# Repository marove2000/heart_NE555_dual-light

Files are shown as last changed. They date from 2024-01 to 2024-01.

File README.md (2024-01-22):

# Heart SMD NE555
24 LEDs forming a LED-Heart driven by a NE555 bistable vibrator. A LED-Light runs around the heart. The speed of the running LED-light can be modified by the potentiomenter
This soldering Kit requires first experience in SMD-Soldering and is a very good practice for the size 0805.

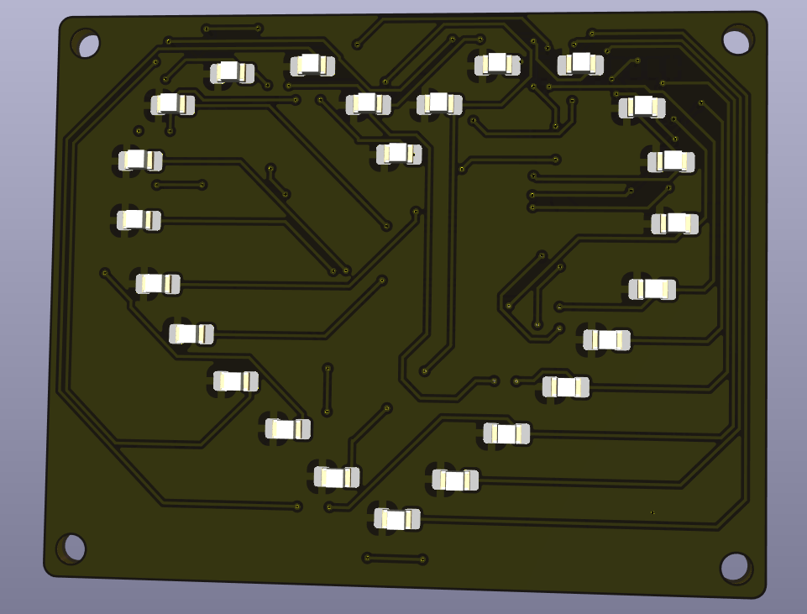
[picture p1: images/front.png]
Heart SMD NE555 dual-led
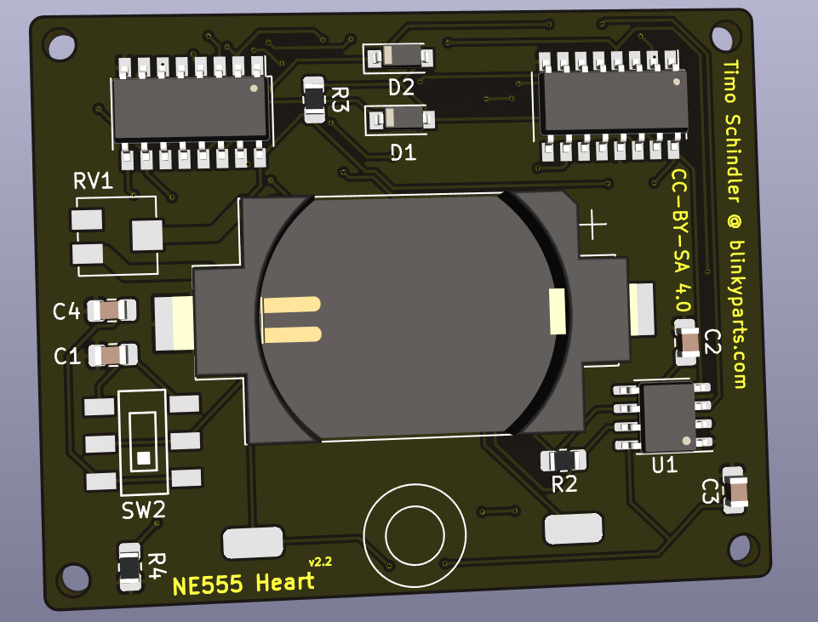
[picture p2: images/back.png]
Heart SMD NE555 dual led
 

- Status: **Complete**
- Difficulty: **3/5**

### Parts List

| Description |  Name  | Quantity |
|---|:---:|:---:|
| SMD LED 0805 red | D5-D28 | 24 |
| SMD Capacitor 10nF | C1 | 1 |
| SMD Capacitor 100n |  C2,C3 | 2 |
| SMD Capacitor 1uF		| C4	 | 1 |
| SMD Diode 1N4007 |  D1-D2 | 2 |
| SMD Push Button | SW1  | 1 |
| SMD Sliding Switch | SW2  | 1 |
| RV1 Potentiometer | RV1  | 1 |
| SMD Resistor 0805 1k | R2 | 1 |
| SMD Resistor 0805 100k | R3 | 1 |
| SMD Resistor 0805 47R | R5 | 1 |
| NE555 SOIC-8 | U1 | 1 |
| CD4017 SOP-16 |  U2,U3 | 2 |
| CR2032 Battery Holder (SMD) | BT1  | 1 |
| CR2032 Battery (not included) | | 1 |

### Manual
You can find the manual and pictures of every step here: https://github.com/Binary-Kitchen/SolderingTutorial

### Buy Kits

You can also buy a ready to make soldering-kit @ [shop.blinkyparts.com](https://shop.blinkyparts.com/de/SMD-LED-Herz-mit-NE555-SMD-Bausatz-mit-Herz/blink232542).

### Copyright and Authorship

- Board: [CC-BY-SA 4.0](https://creativecommons.org/licenses/by-sa/4.0/) - [Timo Schindler @ blinkyparts.com](https://shop.blinkyparts.com)
- CR2032 battery holder footprint: [CC-BY 4.0](https://creativecommons.org/licenses/by/4.0/) - Sparkfun (https://github.com/sparkfun/SparkFun-KiCad-Libraries)

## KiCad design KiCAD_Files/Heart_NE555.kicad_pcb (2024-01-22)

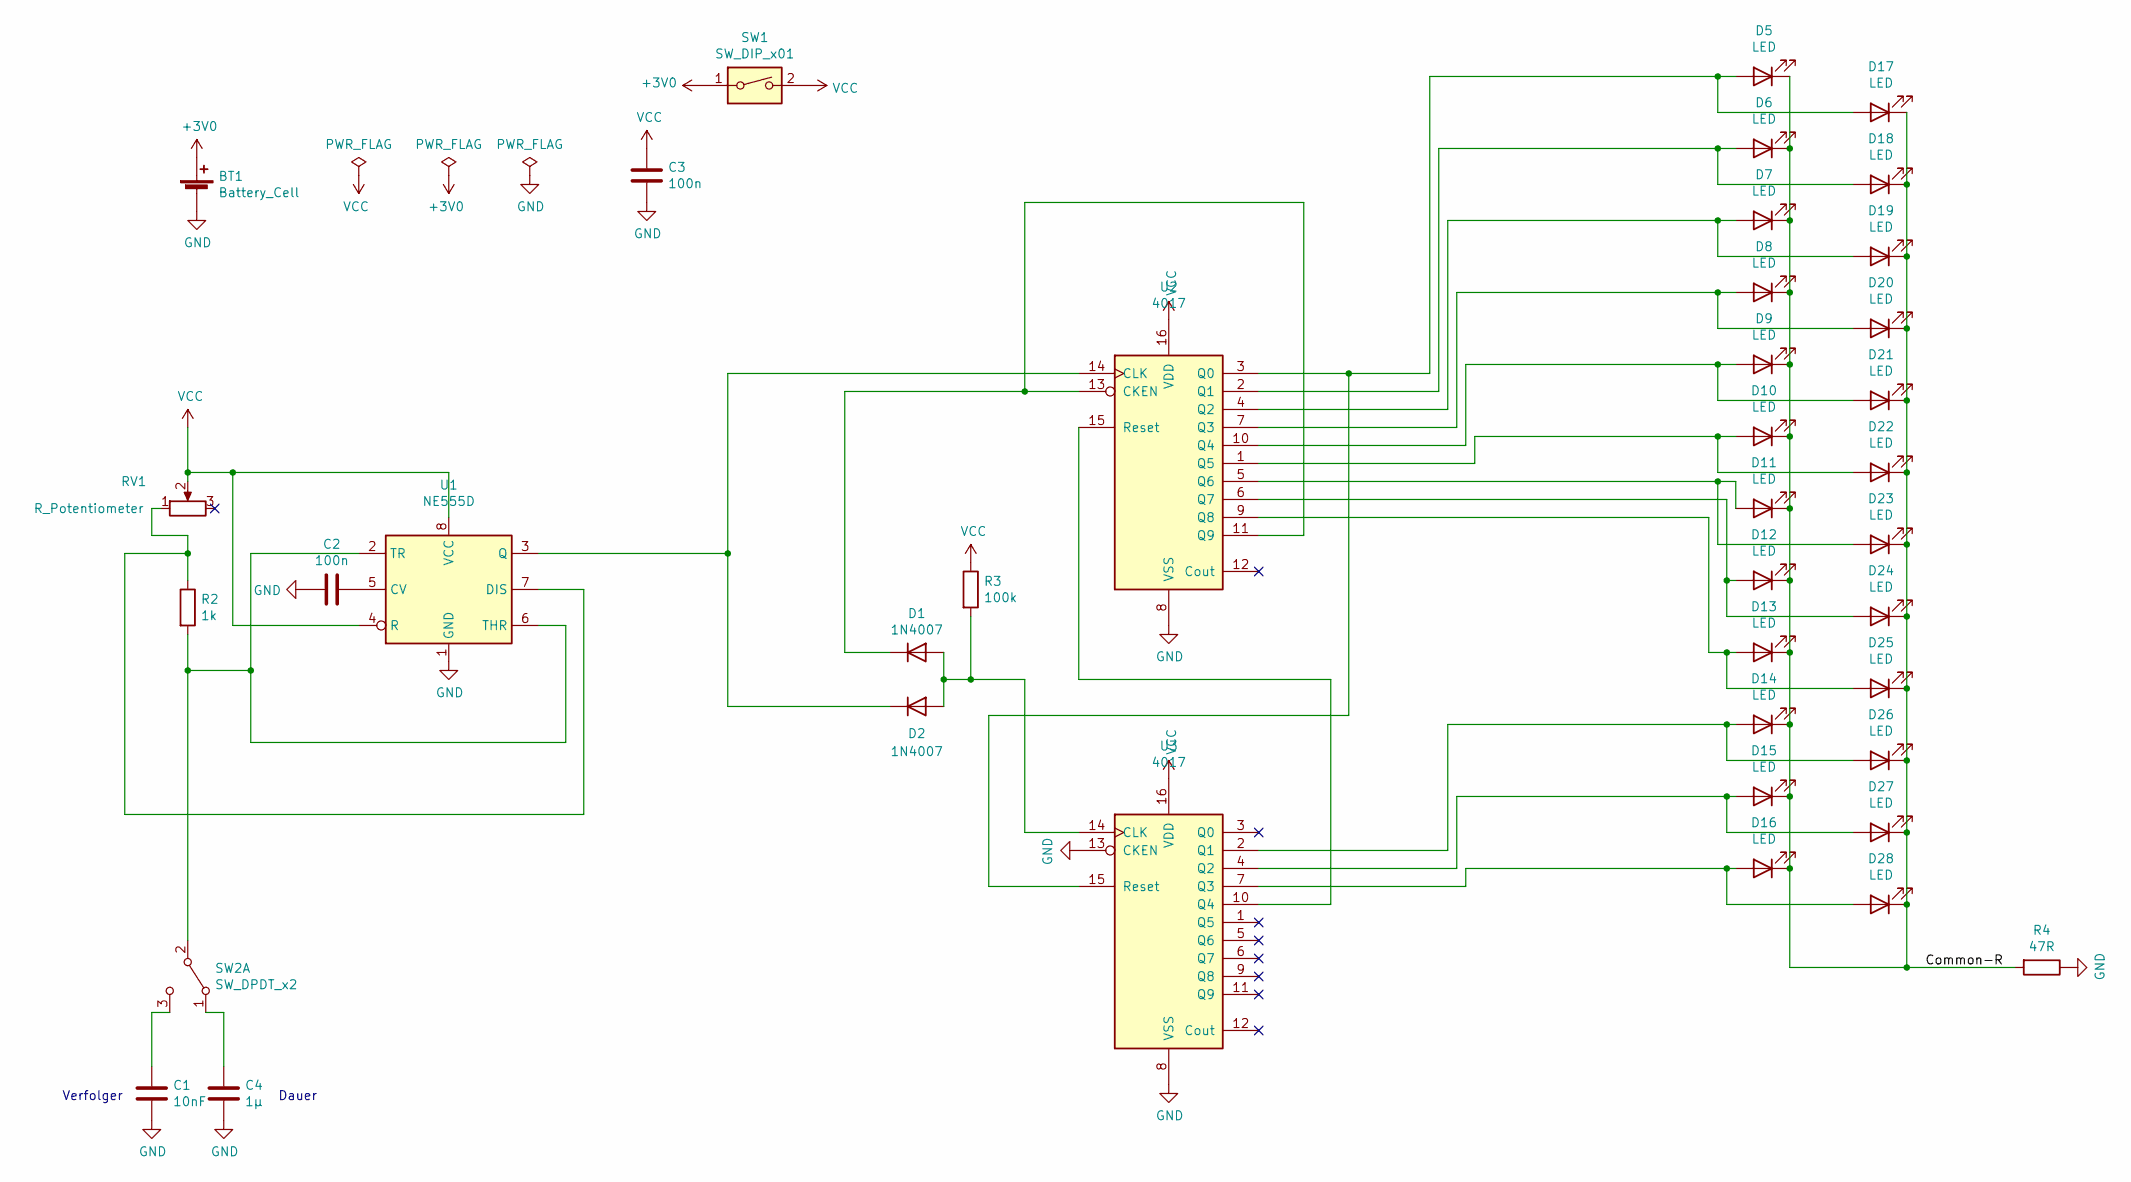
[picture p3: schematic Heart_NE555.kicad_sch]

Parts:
BT1: Battery_Cell; BatteryHolder_Keystone_1060_1x2032_HandSoldering
C1: 10nF; C_0805_2012Metric_Pad1.18x1.45mm_HandSolder
C2, C3: 100n; C_0805_2012Metric_Pad1.18x1.45mm_HandSolder
C4: 1µ; C_0805_2012Metric_Pad1.18x1.45mm_HandSolder
D1, D2: 1N4007; D_SOD-123_handsolder
D5, D6, D7, D8, D9, D10, D11, D12, D13, D14, D15, D16, D17, D18, D19, D20, D21, D22, D23, D24, D25, D26, D27, D28: LED; LED_0805_2012Metric_Pad1.15x1.40mm_HandSolder
R2: 1k; R_0805_2012Metric_Pad1.20x1.40mm_HandSolder
R3: 100k; R_0805_2012Metric_Pad1.20x1.40mm_HandSolder
R4: 47R; R_0805_2012Metric_Pad1.20x1.40mm_HandSolder
RV1: R_Potentiometer; Potentiometer_Vishay_TS53YJ_Vertical
SW1: SW_DIP_x01; Push_Button
SW2: SW_DPDT_x2; smd_switch_slide
U1: NE555D; SOIC-8_3.9x4.9mm_P1.27mm
U2, U3: 4017; SOP-16_4.4x10.4mm_P1.27mm

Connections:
+3V0: BT1.1 (+), SW1.1
/Common-R: D5.1 (K), D6.1 (K), D7.1 (K), D8.1 (K), D9.1 (K), D10.1 (K), D11.1 (K), D12.1 (K), D13.1 (K), D14.1 (K), D15.1 (K), D16.1 (K), D17.1 (K), D18.1 (K), D19.1 (K), D20.1 (K), D21.1 (K), D22.1 (K), D23.1 (K), D24.1 (K), D25.1 (K), D26.1 (K), D27.1 (K), D28.1 (K), R4.2
GND: BT1.2 (-), C1.2, C2.2, C3.2, C4.2, R4.1, U1.1 (GND), U2.8 (VSS), U3.8 (VSS), U3.13 (CKEN)
unnamed: C1.1, SW2.3 (C)
unnamed: C2.1, U1.5 (CV)
unnamed: C4.1, SW2.1 (A)
unnamed: D1.1 (K), U2.11 (Q9), U2.13 (CKEN)
unnamed: D1.2 (A), D2.2 (A), R3.2, U3.14 (CLK)
unnamed: D2.1 (K), U1.3 (Q), U2.14 (CLK)
unnamed: D10.2 (A), D22.2 (A), U2.1 (Q5)
unnamed: D11.2 (A), D23.2 (A), U2.5 (Q6)
unnamed: D12.2 (A), D24.2 (A), U2.6 (Q7)
unnamed: D13.2 (A), D25.2 (A), U2.9 (Q8)
unnamed: D14.2 (A), D26.2 (A), U3.2 (Q1)
unnamed: D15.2 (A), D27.2 (A), U3.4 (Q2)
unnamed: D16.2 (A), D28.2 (A), U3.7 (Q3)
unnamed: D5.2 (A), D17.2 (A), U2.3 (Q0), U3.15 (Reset)
unnamed: D6.2 (A), D18.2 (A), U2.2 (Q1)
unnamed: D7.2 (A), D19.2 (A), U2.4 (Q2)
unnamed: D8.2 (A), D20.2 (A), U2.7 (Q3)
unnamed: D9.2 (A), D21.2 (A), U2.10 (Q4)
unnamed: R2.1, RV1.1, U1.7 (DIS)
unnamed: R2.2, SW2.2 (B), U1.2 (TR), U1.6 (THR)
unnamed: U2.15 (Reset), U3.10 (Q4)
VCC: C3.1, R3.1, RV1.2, SW1.2, U1.4 (R), U1.8 (VCC), U2.16 (VDD), U3.16 (VDD)

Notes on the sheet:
Verfolger
Dauer

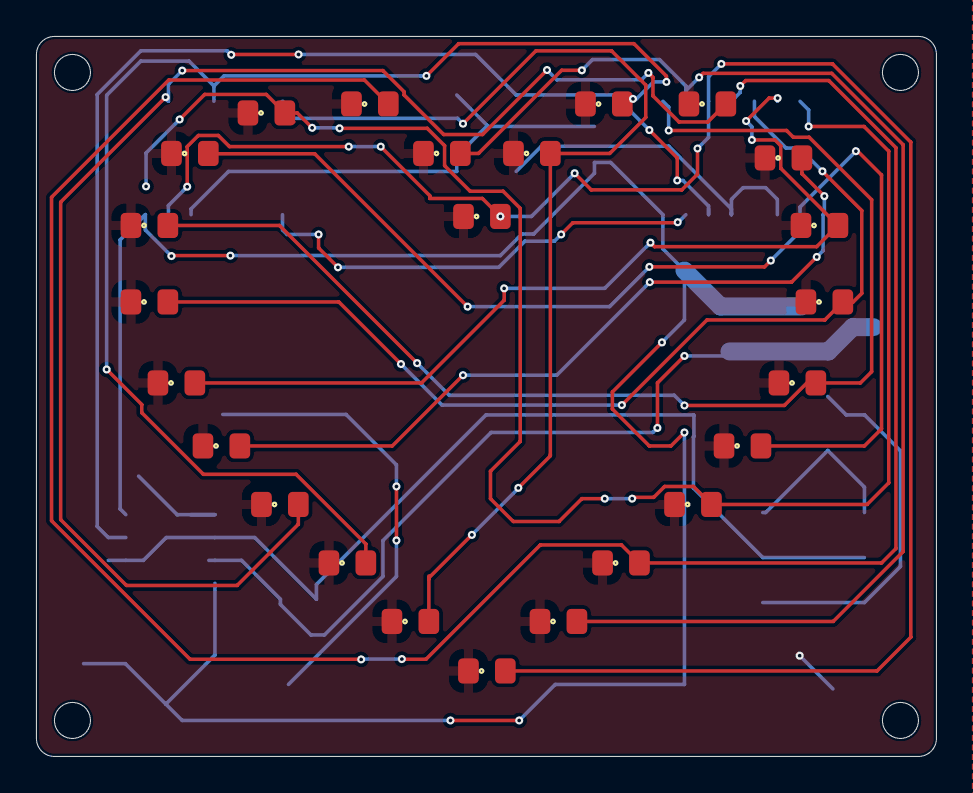
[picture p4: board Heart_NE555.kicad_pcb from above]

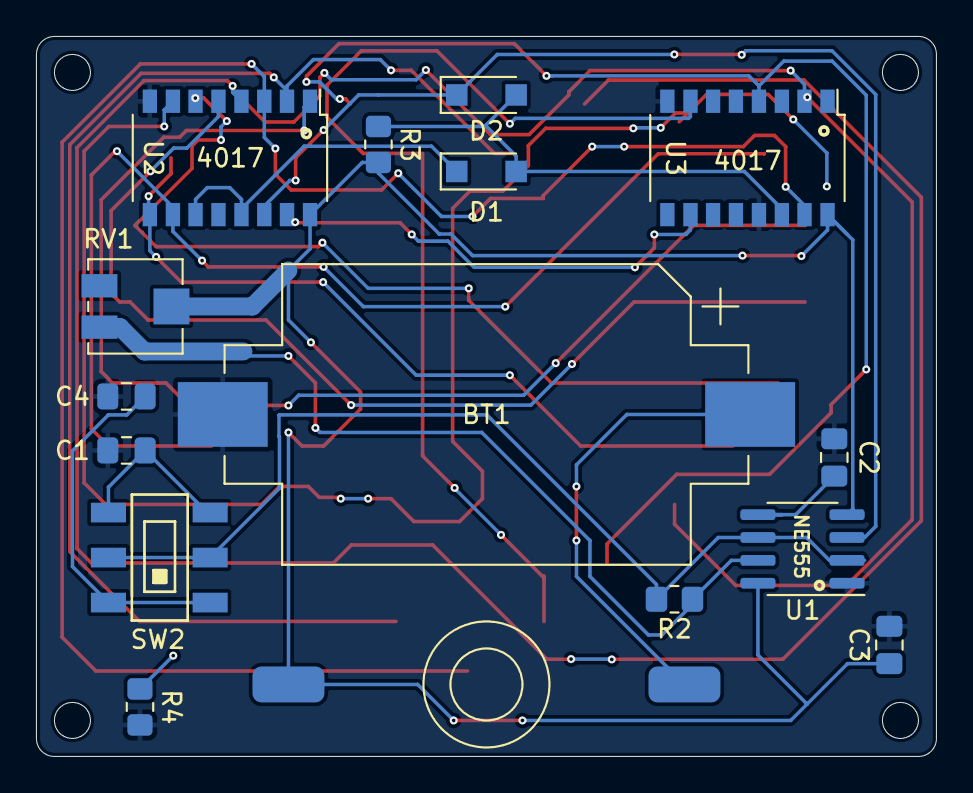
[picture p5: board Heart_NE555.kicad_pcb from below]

Board: 2 copper layers, 50.0 x 40.0 mm, 40 parts (16 on the bottom side), 25 nets.
